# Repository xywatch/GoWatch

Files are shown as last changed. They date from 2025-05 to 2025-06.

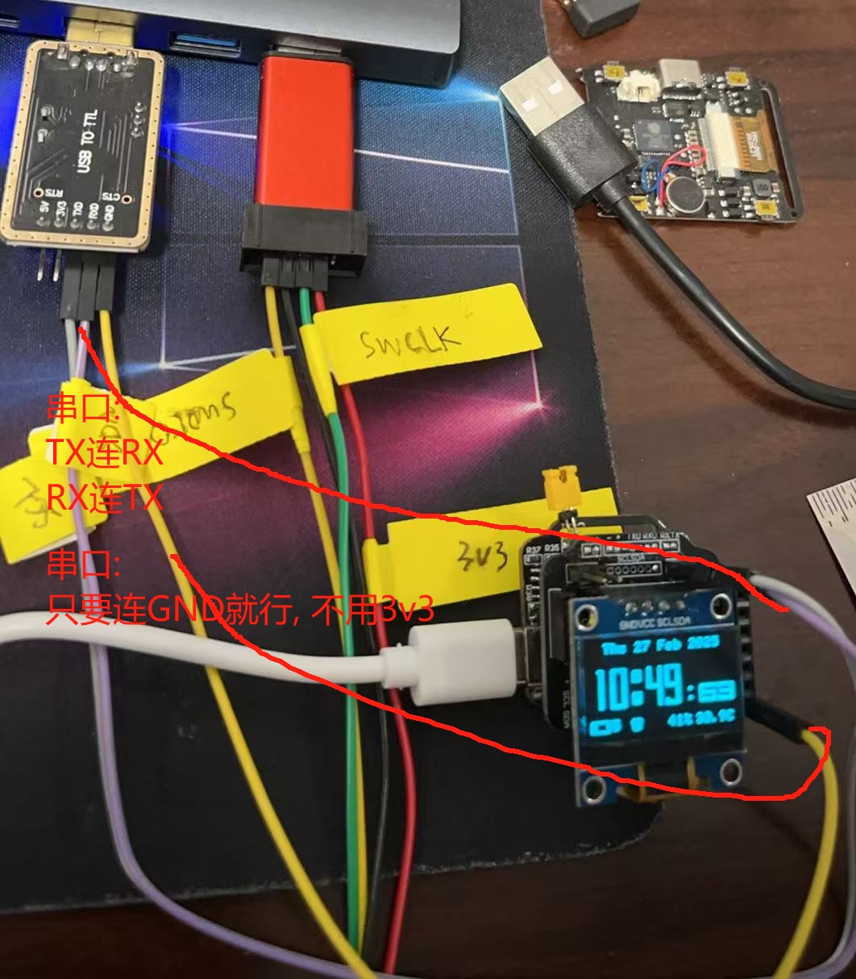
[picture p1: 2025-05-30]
docs/串口调试.jpg

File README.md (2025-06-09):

# GoWatch v1
GoWatch v1 - An Open Source Smartwatch based on STM32f103CBT6

## Main hardware
* STM32f103CBT6
* DS3231
* mpu6050
* bme280
* OLED 0.96

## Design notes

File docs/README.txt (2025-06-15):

# 文件结构

USER/GOWATCH.uvprojx 这个文件可以修改Group, 头文件, 其它的GOWATCH.xxx文件都是自动生成的, 不要修改
Group不能嵌套

# POWER_ON
PA1

main.c
void power_pin_init(void)
{
    GPIO_InitTypeDef GPIO_InitStructure;
    RCC_APB2PeriphClockCmd(RCC_APB2Periph_GPIOA, ENABLE);
    GPIO_InitStructure.GPIO_Pin = GPIO_Pin_1;        //	 PA1 POWER 控制端口
    GPIO_InitStructure.GPIO_Mode = GPIO_Mode_Out_PP; // 推挽输出
    GPIO_InitStructure.GPIO_Speed = GPIO_Speed_2MHz; // 速度
    GPIO_Init(GPIOA, &GPIO_InitStructure);
    GPIO_SetBits(GPIOA, GPIO_Pin_1); // 设为高电平, 开机
}

my_menu.c
// 关机
void ShutDown(void)
{
    // display_startCRTAnim(CRTANIM_CLOSE);
    GPIO_ResetBits(GPIOA, GPIO_Pin_1);
}

# 
PA1=TIM2_CH2
TIM2_CH1用于beep播放音乐, 导致TIM2_CH2也受影响, 播放时可能会拉低PA1, 关机. 不会!! 只配置了TIM2_CH1
对TIM2_CH2没有影响, 感觉是电压不稳定导致
播放音乐, mpu都会导致重启

排查到是电池管理芯片TP4057有问题, 电压不稳定

# OLED

PB15 SCL
PB14 SDA
oled_driver.h
oled_driver.c

# OLED 1.3 & 0.96

oled_driver.h

#if defined(SSD1306) 0.96
#define __SET_COL_START_ADDR() 	do { \
        ssd1306_write_byte(0x00, SSD1306_CMD); \
        ssd1306_write_byte(0x10, SSD1306_CMD); \
    } while(false)
#elif defined(SH1106) 1.3
#define __SET_COL_START_ADDR() 	do { \
        ssd1306_write_byte(0x02, SSD1306_CMD); \
        ssd1306_write_byte(0x10, SSD1306_CMD); \
    } while(false)
#endif

# key

PB1 上 右
PA7 中
PA3 下 左
buttons.h
buttons.c

改成

PB1 上 右
PA5 中
PA4 下 左
buttons.h
buttons.c

nvic.c 按键中断也要配置

# 内部RTC与DS3231切换

config.h

# DS3231, MPU6050 SCL2, SDA2
SCL2 PB8
SDA2 PB9

在 i2c_soft.h中改成

SCL2 PA7
SDA2 PB0

# font

english.h 默认的

# mpu6050

mpu/mpu6050.h

//如果AD0脚(9脚)接地,IIC地址为0X68(不包含最低位).
//如果接V3.3,则IIC地址为0X69(不包含最低位).
//注意！！！！！！！！！！！！
//默认0x68时会与DS3231的0xD0,0XD1冲突故选择AD0上拉至VCC
#define MPU_ADDR				0X69// INV_MPU.c内的0x68已经均改为0x69

外接要改成 0x68

# mpu方向设置 inv_mpu.v

//陀螺仪方向设置 默认
/*
https://blog.csdn.net/BinHeon/article/details/110925168
--------------->y
     |
     |
     |
    \ /
     x
     Z正方向屏幕向外

static signed char gyro_orientation[9] = { 1, 0, 0,
                                           0, 1, 0,
                                           0, 0, 1};
                                           
变成
------------>x
   |
   y
*/

static signed char gyro_orientation[9] = { 
    0, 1, 0,
    1, 0, 0,
    0, 0, 1
};

变成
x<-----
   |
   y
*/

static signed char gyro_orientation[9] = { 
    0, -1, 0,
    1, 0, 0,
    0, 0, 1
};

变成
    y
   |
   |
------------>x

*/

static signed char gyro_orientation[9] = { 
    0, 1, 0,
    -1, 0, 0,
    0, 0, 1
};

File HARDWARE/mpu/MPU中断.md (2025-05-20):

python:

抬头检测
https://blog.51cto.com/u_16213671/12014295

MPU6050配置中断读取数据
https://blog.csdn.net/shaynerain/article/details/102970135

MPU6050 / MPU6000配置中断寄存器后INT电平一直不变（为高），解决办法：
https://blog.csdn.net/m0_37777700/article/details/84874375

STM32配置FIFO中断，并控制中断时间
https://blog.csdn.net/qq_46554815/article/details/113653451

V8 int引角为 PB11

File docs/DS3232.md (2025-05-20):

void DS3231_Set_alarm1(void)
{
    alarm_s alarm;
    if (!alarm_getNext(&alarm))
    {
        printf("DS3231 alarm is not set\n");
        // 清空闹钟
        // 在 DS3231 中，闹钟寄存器的每个字节的最高位（bit 7）是闹钟匹配标志位（A1M1-A1M4），用来控制是否需要该位匹配：
        // 0 = 需要匹配
        // 1 = 忽略匹配
        // 正确的做法是设置所有匹配位（A1Mx）为 1，表示忽略所有匹配条件：
        // 0x80 = 1000 0000，最高位为 1，表示忽略该时间位的匹配
        // 这样闹钟就不会在任何时间触发
        DS3231_WR_Byte(Alarm1_Address_Second, 0x80);  // A1M1=1，忽略秒匹配
        DS3231_WR_Byte(Alarm1_Address_Minute, 0x80);  // A1M2=1，忽略分钟匹配
        DS3231_WR_Byte(Alarm1_Address_Hour, 0x80);    // A1M3=1，忽略小时匹配
        DS3231_WR_Byte(Alarm1_Address_Week, 0x80);    // A1M4=1, 忽略日期/星期匹配
        return;
    }

    u8 temp_a = 0;

    printf("DS3231 alarm days: %d, hour: %d, min: %d\n", alarm.days, alarm.hour, alarm.min);

    // 1 闹钟1星期0~7位设定
    // 0X0A用于星期计数时8位应满足 x1xx xxxx
    //  &0x0f；      //数据变为：0000 xxxx//由于0X0A里用于星期计数时只有低四位有效，故通过&0x0f屏蔽高四位的设定，（同时会导致高四位为0，当0X0A第6位为0时变更为日期闹钟计数，0X0A第7位为0）故有以下办法
    //  &0x0f | (1<<6);//数据变为：0100 xxxx//将0X0A第6位置1，则将按星期闹钟计数，当第7位A1M4为1时该位无影响，此时闹钟只有在星期也匹配后才会响
    //  &0x0f | (3<<6);//数据变为：1100 xxxx//0X0A第7位A1M4为1，第6位在闹钟配置里失效，只要时间匹配闹钟就会响

    // B_BCD(alarm.days) & 0x0f 只保留后4位
    // temp_a = B_BCD(alarm.days) & 0x0f | (1 << 6);
    // DS3231_WR_Byte(Alarm1_Address_Week, temp_a);

    DS3231_WR_Byte(Alarm1_Address_Week, 0x80);    // A1M4=1，忽略日期/星期匹配

    // 2 闹钟1小时设定

    // & 0X3F 数据变为：00xx xxxx
    // 0X09中第6位为0时采用24h制，第7位A1M3为0时, 启用A1M3
    // bit 7: A1M3 (闹钟匹配位)
    // bit 6: 12/24小时制选择位 (1=12小时制, 0=24小时制)
    // bit 5-0: 小时的 BCD 值 (0-23 或 1-12)
    // temp_a = B_BCD(alarm.hour) & 0X3F 可以不用, 因为小时的BCD值最大为0x23, 6, 7位肯定为0
    temp_a = B_BCD(alarm.hour);
    DS3231_WR_Byte(Alarm1_Address_Hour, temp_a);

    // 3 闹钟1分钟设定

    // 通过&0x7f屏蔽最高第七位的标志位,启用A1M2
    // 数据变为：0xxx xxxx
    // temp_a = B_BCD(alarm.min) & 0x7f; // 屏蔽最高位, 转换后的值范围是 0x00-0x59，最高位本来就是 0, 所以可以不用  & 0x7f
    temp_a = B_BCD(alarm.min);
    DS3231_WR_Byte(Alarm1_Address_Minute, temp_a);

    // 4 闹钟1秒设定

    // 通过&0x7f屏蔽最高第七位的标志位,启用A1M1
    // 数据变为：0xxx xxxx
    // temp_a = B_BCD(0) & 0x7f; // 屏蔽最高位
    // DS3231_WR_Byte(Alarm1_Address_Second, temp_a);

    // 设置秒 - A1M1=1，忽略秒匹配
    DS3231_WR_Byte(Alarm1_Address_Second, 0x80);

    // 读取并打印所有相关寄存器的值进行调试
    printf("DS3231 Registers after alarm set:\n");
    printf("Control(0x0E): 0x%02X\n", DS3231_RD_Byte(Address_control));
    printf("Status(0x0F): 0x%02X\n", DS3231_RD_Byte(Address_control_status));
    printf("Alarm1 Second: 0x%02X\n", DS3231_RD_Byte(Alarm1_Address_Second));
    printf("Alarm1 Minute: 0x%02X\n", DS3231_RD_Byte(Alarm1_Address_Minute));
    printf("Alarm1 Hour: 0x%02X\n", DS3231_RD_Byte(Alarm1_Address_Hour));
    printf("Alarm1 Week/Date: 0x%02X\n", DS3231_RD_Byte(Alarm1_Address_Week));
}
OKBme280_WriteData OKBme280_WriteData OKSetting alarm for 21:34
Next alarm day: 3

Alarm Configuration Verification:
Day conversion: 3 -> 5 (DS3231 format)
Time: 21:34:00
Week register: 0x45
Control: 0x05, Status: 0x00

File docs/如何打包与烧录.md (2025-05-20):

见图片

问题: 为什么不能选STM32F103C8?

可以选, 且需要 STM32F10X_MD, 但编译报没有空间:
..\OBJ\REMOTE.axf: Error: L6406E: No space in execution regions with .ANY selector matching resources.o(.constdata).

为什么选ZE, STM32F10X_MD 下载体积过大也没事

--c99 -c --cpu Cortex-M3 -D__MICROLIB -g -O2 --apcs=interwork -I..\HARDWARE\LED -I..\SYSTEM\delay -I..\SYSTEM\sys -I..\SYSTEM\usart -I..\USER -I..\STM32F10x_FWLib\inc -I..\CORE -I..\HARDWARE\REMOTE -I..\HARDWARE\KEY -I..\HARDWARE\OLED -I..\HARDWARE\BEEP -I..\Watch -I..\HARDWARE -I..\HARDWARE\mpu -I..\HARDWARE\mpu\eMPL -I..\WATCH -I..\Watch\GameLife 
-I C:\Users\lt\Desktop\go-watch\USER\RTE 
-I D:\Keil_v5\ARM\PACK\Keil\STM32F1xx_DFP\1.0.5\Device\Include 
-I D:\Keil_v5\ARM\CMSIS\Include 
-D__UVISION_VERSION="514" -DSTM32F10X_HD -DSTM32F10X_HD -DUSE_STDPERIPH_DRIVER -o "..\OBJ\*.o" --omf_browse "..\OBJ\*.crf" --depend "..\OBJ\*.d"

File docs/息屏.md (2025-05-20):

所以息屏的工作流程是：
系统默认设置20秒（appConfig.sleepTimeout = 4）的息屏超时时间
每次按键都会更新 buttons[i].pressedTime
在 pwrmgr_update() 中检查是否有按钮活动
如果超过20秒没有按键，就会触发息屏动画（CRTANIM_CLOSE）
息屏后可以通过按键或MPU6050检测到的运动来唤醒
你可以通过修改 appConfig.sleepTimeout 的值来调整息屏时间：
4 = 20秒
3 = 15秒
2 = 10秒
0 = 禁用息屏

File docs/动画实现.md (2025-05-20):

# 动画实现说明

本项目实现了两种主要的过渡动画：

## 1. 滑动动画（Slide Animation）

- 通过 `animation_start()` 函数实现，支持两种方向：
  - `ANIM_MOVE_ON`：从上往下滑动（开启界面）
  - `ANIM_MOVE_OFF`：从下往上滑动（关闭界面）
- 核心实现在 `animation.c` 中：
  ```c
  void animation_update() {
      if (animationStatus.active) {
          byte offsetY = animationStatus.offsetY;
          if (animationStatus.goingOffScreen) {
              // 向上滑动的速度控制
              if (offsetY < 4) offsetY += 1;
              else if (offsetY < 8) offsetY += 3;
              else if (offsetY < 16) offsetY += 5;
              else offsetY += 8;
          } else {
              // 向下滑动的速度控制
              if (offsetY > 255 - 4) offsetY += 1;
              else if (offsetY > 255 - 8) offsetY += 3;
              else if (offsetY > 255 - 16) offsetY += 5;
              else offsetY += 8;
          }
          // ...
      }
  }
  ```

## 2. CRT 动画（开/关屏动画）

- 通过 `display_startCRTAnim()` 函数实现，支持：
  - `CRTANIM_OPEN`：开屏动画 中间往上往下展开
  - `CRTANIM_CLOSE`：关屏动画 上下往中间关闭
- 在 `display.c` 中实现：
  ```c
  void display_startCRTAnim(crtAnim_t open) {
      if (open == CRTANIM_OPEN) {
          crt_anim.closing = false;
          crt_anim.height = FRAME_HEIGHT / 2;
      } else {
          crt_anim.closing = true;
          crt_anim.height = 0;
      }
      crt_anim.active = true;
  }
  ```

## 动画的使用场景

1. 菜单切换：
```c
void mMainOpen() {
    exitMeThenRun(mOpen);  // 关闭动画
}
```

2. 返回上一级：
```c
static bool btnExit() {
    animation_start(back, ANIM_MOVE_OFF);  // 带关闭动画的退出
    return true;
}
```

3. 开关屏：
```c
void userWake() {
    display_startCRTAnim(CRTANIM_OPEN);  // 开屏动画
}
```

## 动画的控制

1. 可以通过设置开关控制是否启用动画：
```c
if (appConfig.animations) {
    animationStatus.active = true;
    // ...
}
```

2. 可以调整动画帧率：
```c
byte fps = MY_FPS / 2;
fps++;
if (fps > 30) fps = 10;
MY_FPS = fps * 2;
```

这些动画效果让界面切换更加流畅自然，提升了用户体验。

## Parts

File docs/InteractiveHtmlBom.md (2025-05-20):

1. 运行一次Initianlize.bat Run Initialize.bat once. (以管理员权限运行, 只运行一次即可, 每次重启都要运行一次)
2. 用AD打开InteractiveHtmlBomForAD.PrjScr
3. 打开pcb文件，打开Run Script...窗口，运行main()函数，生成ibom。

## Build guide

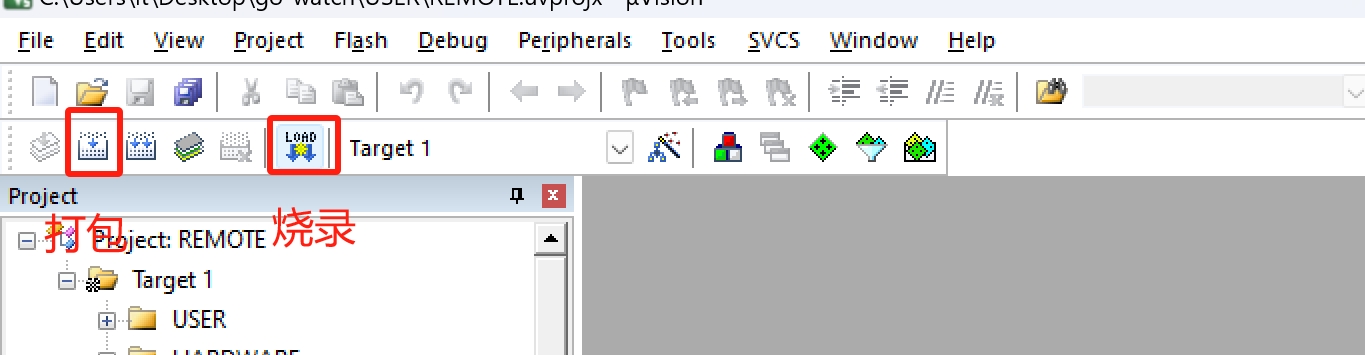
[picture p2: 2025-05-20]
docs/4build&upload.png

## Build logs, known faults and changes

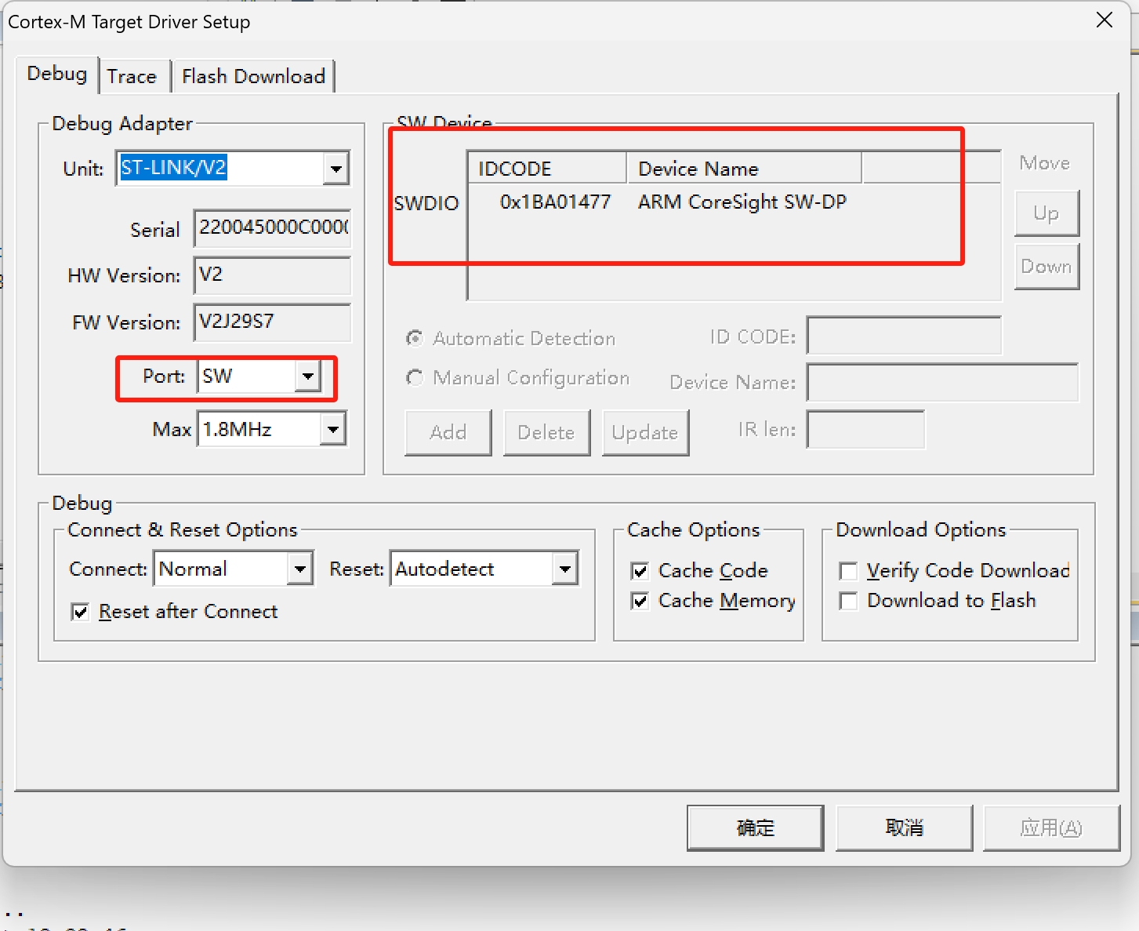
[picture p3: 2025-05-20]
docs/3debug2.png

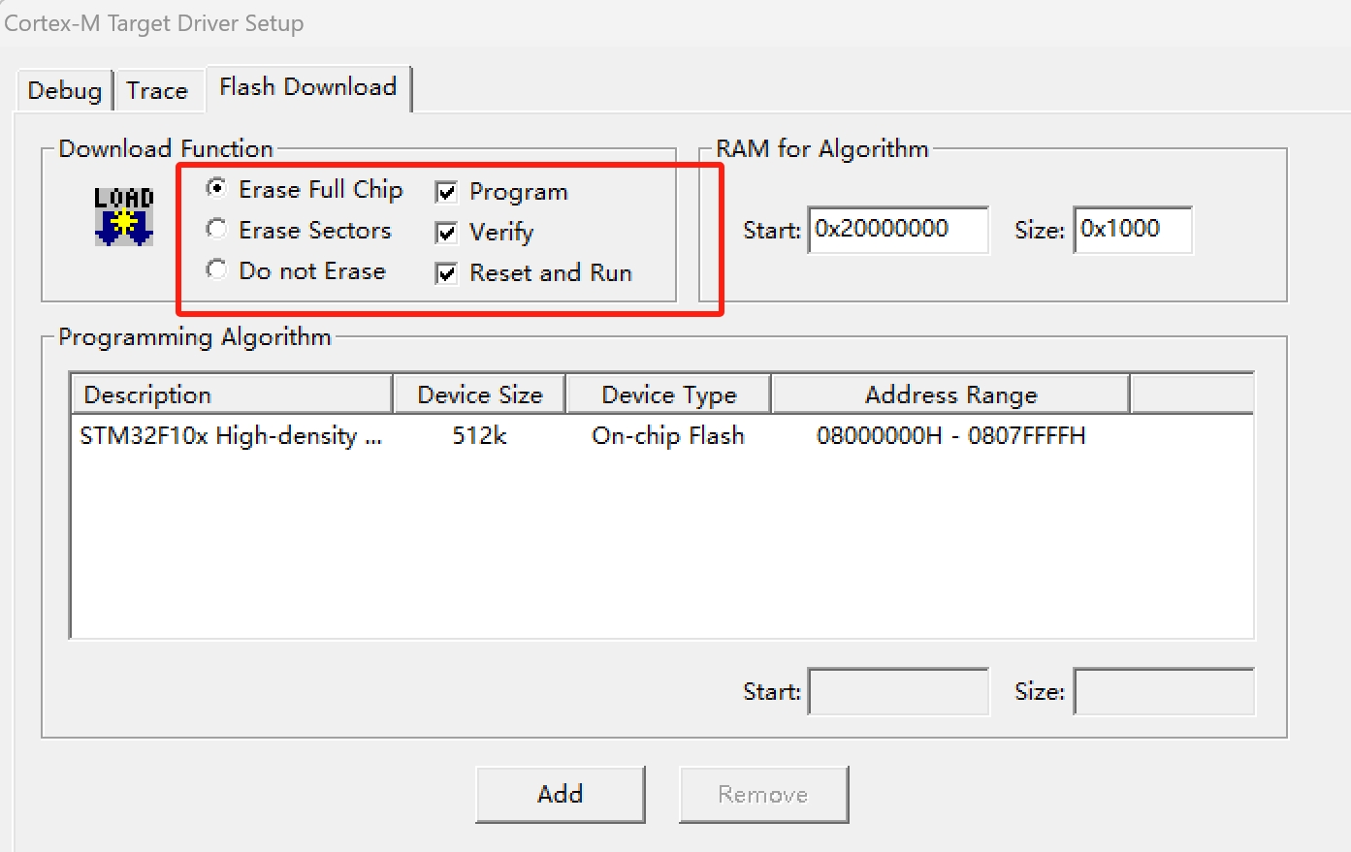
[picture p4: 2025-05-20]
docs/3debug3.png

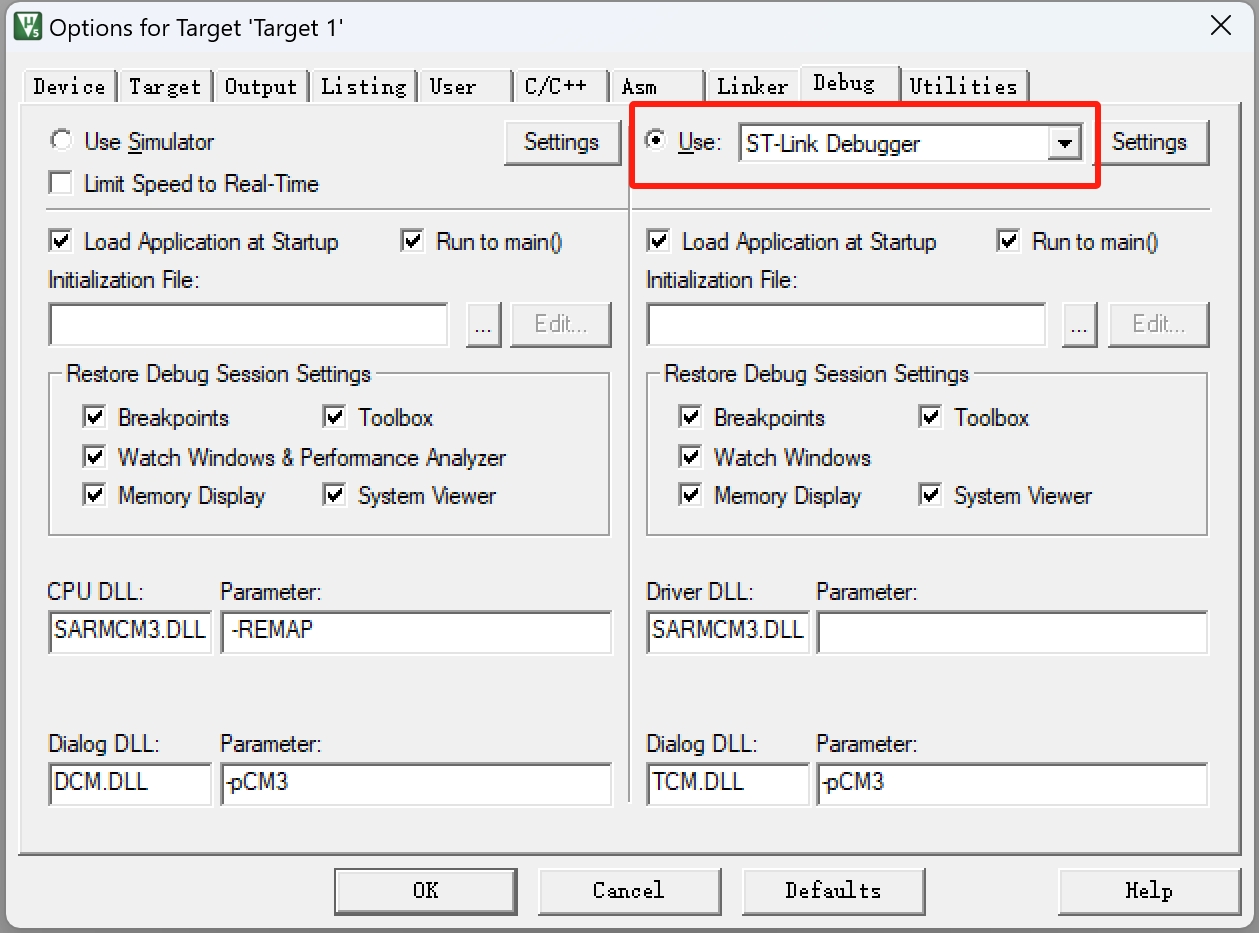
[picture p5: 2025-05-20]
docs/3debug.png

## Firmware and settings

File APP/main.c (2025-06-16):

#include "common.h"

void power_pin_init(void)
{
    GPIO_InitTypeDef GPIO_InitStructure;
    RCC_APB2PeriphClockCmd(POWER_ON_PORT == GPIOA ? RCC_APB2Periph_GPIOA : RCC_APB2Periph_GPIOB, ENABLE);
    GPIO_InitStructure.GPIO_Pin = POWER_ON_PIN;        //	 PA1 POWER 控制端口
    GPIO_InitStructure.GPIO_Mode = GPIO_Mode_Out_PP; // 推挽输出
    GPIO_InitStructure.GPIO_Speed = GPIO_Speed_2MHz; // 速度
    GPIO_Init(POWER_ON_PORT, &GPIO_InitStructure);
    GPIO_SetBits(POWER_ON_PORT, POWER_ON_PIN); // 设为高电平, 开机
}

void showSpace()
{
    byte width = 52;
    byte height = 48;
    byte x = (128 - width) / 2;
    byte y = (64 - height) / 2;
    u16 delayMs = 100;
    byte count = 2; // 循环次数

    const u8 *space_images[] = {
        space_image1, space_image2, space_image3, space_image4, space_image5,
        space_image6, space_image7, space_image8, space_image9, space_image10};
  
    while (count--)
    {
      for (int i = 0; i < 10; i++)
      {
        draw_bitmap(x, y, space_images[i], width, height, NOINVERT, 0);
        OLED_Flush();
        OLED_ClearScreenBuffer();
        delay_ms(delayMs);
      }
    }
}

extern short pitch_a, roll_a, yaw_a;
void c_setup()
{
    power_pin_init();
    // SystemInit();
    // NVIC_PriorityGroupConfig(NVIC_PriorityGroup_2);// 设置中断优先级分组2
    delay_init();                                   // 延时函数初始?
    NVIC_PriorityGroupConfig(NVIC_PriorityGroup_2); // 设置系统中断优先级分组2

    uart_init(115200);
    printf("go1\n");

    OLED_Init(); // 初始化OLED接口
    Adc_Init();  // ADC初始化
    KEY_INT_INIT(); // 按键中断
    millis_init();
    printf("go2\n");

    delay_ms(50);
    showSpace();
    
    appconfig_init();

    console_log(50, "Init MPU...");
    // console_log(50, "SS %d", SystemCoreClock);

    char i = 0;
    int count = 0;

    i = MPU_Init(); // 不要用因为下面mpu_dmp_init会重新init

    while (i != 0 && i != 1 && count++ < 3)
    {
        printf("MPU Init %d\n", i);
        console_log(50, "MPU Init %d", i);
        delay_ms(50);
        i = MPU_Init(); // 不要用因为下面mpu_dmp_init会重新init
    }

    I2C_GPIO_Config();
    i = mpu_dmp_init();
    printf("mpu_dmp_init %d\n", i);
    count = 0;

    while ((++count) < 10 && i)
    {
        // i = MPU_Init(); // 不要用因为下面mpu_dmp_init会重新init
        // printf("MPU_Init %d\n", i);
        //  console_log(1, "MPU Init:%d", i);
        console_log(50, "MPU DUM Error %d", i);
        delay_ms(50);
        i = mpu_dmp_init();
        printf("mpu_dmp_init error %d\n", i);
    }

    if (!i)
    {
        console_log(50, "Init MPU OK");
    }
    else
    {
        console_log(50, "Init MPU Error");
    }
    if (appConfig.moveCheckFlag) {
        MPU_INT_Init();
    }
    
    milliseconds = 0;

    // 然后初始化 DS3231
    DS3231_Init();      // DS3231初始化
    delay_ms(10);       // 等待初始化完成

    // 初始化中断引脚
    RTC_INT_INIT();
    console_log(50, "DS3231 Init OK");

    // time_init();
    // Date_init();
    // ds3231只用电池供电, 所以必须要焊接电池
    // 如果ds3231有问题, 就会一直卡在Start! 可能5v导致ds3231死机, 此时需要电池下电
    DS3231_Get_Time();
    if (timeDate.time.secs == 0 && timeDate.time.mins == 0 && timeDate.time.hour == 0) {
        console_log(50, "Set default date");
        // 那不是每次都重置了rtc时间
        time_s time = {0, 39, 10, 'A'};
        date_s date = {DAY_THU, 27, MONTH_FEB, 25};
        timeDate.time = time;
        timeDate.date = date;
        DS3231_Set_Date();
        DS3231_Set_Time();
    }

    led_init();
    buzzer_init();
    buttons_init();

    Bme280_Init();
    console_log(50, "BME Init OK");

    alarm_init();

    pwrmgr_init();
    console_log(50, "START !");

    // memset(&oledBuffer, 0x00, FRAME_BUFFER_SIZE);
    OLED_ClearScreenBuffer();

    // Set watchface
    display_set(watchface_normal);
    display_load(); // 启动表盘
}

extern bool MPU6050_WakeUpRequested;
extern bool DeepSleepFlag;
extern bool SleepRequested;
void c_loop()
{
    // mpu6050 唤醒
    if (MPU6050_WakeUpRequested) {
        // 1. 先恢复时钟
        RCC_Configuration();
        delay_ms(10);  // 等待时钟稳定

        printf("MPU6050_WakeUpRequested\n");
        
        // 2. 再检查运动
        if (MPU_movecheck()) {
            printf("mpu6050 movecheck\n");
            nvic_wake_up(50);
            SleepRequested = false; // 避免在mpu6050唤醒后处理休眠请求
        }
        else {
            printf("mpu6050 not move\n");
            // 如果mpu6050没有移动, 则会立即执行下面的进入STOP模式
        }

        MPU6050_WakeUpRequested = false;
    }

    // printf("SleepRequested %d, MPU6050_WakeUpRequested %d, DeepSleepFlag %d\n", SleepRequested, MPU6050_WakeUpRequested, DeepSleepFlag);

    // mpu6050 int后虽然没有moveCheck成功, 但其实已经唤醒了, 此时DeepSleepFlag=1
    // mpu6050 唤醒后, 也会触发休眠请求, 所以不要在mpu6050唤醒后处理休眠请求
    if (SleepRequested && !MPU6050_WakeUpRequested) {
        SleepRequested = false;
        nvic_sleep(1);
    }

    time_update();

    // 这里会一直返回true, 除非sleep也就不会执行loop()了
    if (pwrmgr_userActive())
    {
        buttons_update();
    }

    buzzer_update();

#if COMPILE_STOPWATCH
    stopwatch_update();
#endif

    if (pwrmgr_userActive())
    {
        alarm_update();

        // 刷新屏幕
        display_update();
    }

    pwrmgr_update();

    // 显示完成后清除缓冲区
    // memset(&oledBuffer, 0x00, FRAME_BUFFER_SIZE);
    OLED_ClearScreenBuffer();
}

void c_setup2()
{
    delay_init();
    uart_init(115200);
    printf("goxxx\n");

    while (1)
    {
        printf("goxxx\n");
        GPIO_ResetBits(GPIOB, GPIO_Pin_14); // 低
        GPIO_SetBits(GPIOB, GPIO_Pin_15);   // 高
        delay_ms(500);
        GPIO_ResetBits(GPIOB, GPIO_Pin_15); // 低
        GPIO_SetBits(GPIOB, GPIO_Pin_14);   // 高
        delay_ms(500);
    }
}

int main(void)
{
    c_setup(); // 初始化

    while (1)
    {
        c_loop(); // 循环
    }
}

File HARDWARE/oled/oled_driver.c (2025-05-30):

#include "oled_driver.h"
#include "sys.h"
#include "delay.h"

void SW_IIC_Configuration(void)
{
    GPIO_InitTypeDef GPIO_InitStructure;
    RCC_APB2PeriphClockCmd(RCC_APB2Periph_GPIOB, ENABLE); // 使能A端口时钟
    GPIO_InitStructure.GPIO_Pin = GPIO_Pin_15 | GPIO_Pin_14;
    GPIO_InitStructure.GPIO_Mode = GPIO_Mode_Out_PP;  // 推挽输出
    GPIO_InitStructure.GPIO_Speed = GPIO_Speed_50MHz; // 速度50MHz
    GPIO_Init(GPIOB, &GPIO_InitStructure);            // 初始化GPIOD3,6
    GPIO_SetBits(GPIOB, GPIO_Pin_15 | GPIO_Pin_14);
    delay_ms(500);
}

/**********************************************
//IIC Start
**********************************************/
void IIC_Start()
{

    OLED_SCLK_Set();
    OLED_SDIN_Set();
    OLED_SDIN_Clr();
    OLED_SCLK_Clr();
}

/**********************************************
//IIC Stop
**********************************************/
void IIC_Stop()
{
    OLED_SCLK_Set();
    //	OLED_SCLK_Clr();
    OLED_SDIN_Clr();
    OLED_SDIN_Set();
}

void IIC_Wait_Ack()
{
    OLED_SCLK_Set();
    OLED_SCLK_Clr();
}

/**********************************************
// IIC Write byte
**********************************************/

void Write_IIC_Byte(unsigned char IIC_Byte)
{
    unsigned char i;
    unsigned char m, da;
    da = IIC_Byte;
    OLED_SCLK_Clr();

    for (i = 0; i < 8; i++)
    {
        m = da;
        //	OLED_SCLK_Clr();
        m = m & 0x80;

        if (m == 0x80)
        {
            OLED_SDIN_Set();
        }
        else
        {
            OLED_SDIN_Clr();
        }

        da = da << 1;
        OLED_SCLK_Set();
        OLED_SCLK_Clr();
    }
}

/**********************************************
// IIC Write Command
**********************************************/
void WriteCmd(unsigned char dat)
{
    IIC_Start();
    Write_IIC_Byte(0x78); // Slave address,SA0=0
    IIC_Wait_Ack();
    Write_IIC_Byte(0x00); // write command
    IIC_Wait_Ack();
    Write_IIC_Byte(dat);
    IIC_Wait_Ack();
    IIC_Stop();
}

void WriteDat(unsigned char dat)
{
    IIC_Start();
    Write_IIC_Byte(0x78); // D/C#=0; R/W#=0
    IIC_Wait_Ack();
    Write_IIC_Byte(0x40); // write data
    IIC_Wait_Ack();
    Write_IIC_Byte(dat);
    IIC_Wait_Ack();
    IIC_Stop();
}

void WriteDats(unsigned char *dat, uint8_t len)
{
    if (len == 0) return;

    IIC_Start();
    Write_IIC_Byte(0x78); // D/C#=0; R/W#=0
    IIC_Wait_Ack();
    Write_IIC_Byte(0x40); // write data
    IIC_Wait_Ack();

    // Write all data bytes in one transaction
    for (uint8_t i = 0; i < len; i++)
    {
        Write_IIC_Byte(dat[i]);
        IIC_Wait_Ack();
    }

    IIC_Stop();
}

void OLED_FILL(unsigned char BMP[])
{
    u8 i, j;
    unsigned char *p;
    p = BMP;

    for (i = 0; i < 8; i++)
    {
        WriteCmd(0xb0 + i); // page0-page1
        __SET_COL_START_ADDR();

        // WriteCmd(0x02);		//low column start address
        // WriteCmd(0x10);
        for (j = 0; j < 128; j++)
        {
            WriteDat(*p++);
        }
    }
}

void OLED_InitIt(void)
{
    WriteCmd(0xAE); // display off
    WriteCmd(0x20); // Set Memory Addressing Mode
    WriteCmd(0x10); // 00,Horizontal Addressing Mode;01,Vertical Addressing Mode;10,Page Addressing Mode (RESET);11,Invalid
    WriteCmd(0xb0); // Set Page Start Address for Page Addressing Mode,0-7
    WriteCmd(0xc8); // Set COM Output Scan Direction
    WriteCmd(0x00); //---set low column address
    WriteCmd(0x10); //---set high column address
    WriteCmd(0x40); //--set start line address
    WriteCmd(0x81); //--set contrast control register
    WriteCmd(0xff); // 亮度调节 0x00~0xff
    WriteCmd(0xa1); //--set segment re-map 0 to 127
    WriteCmd(0xa6); //--set normal display
    WriteCmd(0xa8); //--set multiplex ratio(1 to 64)
    WriteCmd(0x3F); //
    WriteCmd(0xa4); // 0xa4,Output follows RAM content;0xa5,Output ignores RAM content
    WriteCmd(0xd3); //-set display offset
    WriteCmd(0x00); //-not offset
    WriteCmd(0xd5); //--set display clock divide ratio/oscillator frequency
    WriteCmd(0xf0); //--set divide ratio
    WriteCmd(0xd9); //--set pre-charge period
    WriteCmd(0x22); //
    WriteCmd(0xda); //--set com pins hardware configuration
    WriteCmd(0x12);
    WriteCmd(0xdb); //--set vcomh
    WriteCmd(0x20); // 0x20,0.77xVcc
    WriteCmd(0x8d); //--set DC-DC enable
    WriteCmd(0x14); //
    WriteCmd(0xaf); //--turn on oled panel

    OLED_CLS();
}

void OLED_CLS(void) // 清屏
{
    unsigned char m, n;

    for (m = 0; m < 8; m++)
    {
        WriteCmd(0xb0 + m); // page0-page1
        WriteCmd(0x00);     // low column start address
        WriteCmd(0x10);     // high column start address

        for (n = 0; n < 128; n++)
        {
            WriteDat(0x00);
        }
    }
}

void OLED_ON(void)
{
    WriteCmd(0X8D); // 设置电荷泵
    WriteCmd(0X14); // 开启电荷泵
    WriteCmd(0XAF); // OLED唤醒
}

void OLED_OFF(void)
{
    WriteCmd(0X8D); // 设置电荷泵
    WriteCmd(0X10); // 关闭电荷泵
    WriteCmd(0XAE); // OLED休眠
}

// 初始化图形库，请将硬件初始化信息放入此中
void OLED_DriverInit(void)
{
    SW_IIC_Configuration();
    OLED_InitIt();
}

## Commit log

2025-05-20 ad v1.1 0402 footprint
    [PcbLib.PcbLib, Schlib.SchLib, dispay.SchDoc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]
2025-05-30 oled i2c batch transfer data
